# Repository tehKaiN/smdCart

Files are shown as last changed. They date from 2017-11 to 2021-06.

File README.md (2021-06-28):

# Custom Sega MegaDrive Cartridges

On this repo you will find schematics for SMD carts of various memory size. Each directory is dedicated to cart of given size.

## Current carts

- `512k` - 512 KByte cart based on 27c4001 chip. Home-etching friendly PCB design. Not tested!
- `1m_29f800` - 1 MByte cart based on 29f800 chip. Erasable/programmable using [ROMprg](https://github.com/tehKaiN/ROMprg) project.
- `2m_29f800` - **Untested!** 1-2 MByte cart based on 1-2 29f800 chips. Erasable/programmable using [ROMprg](https://github.com/tehKaiN/ROMprg) project.

## PCB Ordering instructions

MegaDrive carts have thickness of 1.6mm.

## Creating new cart

When designing PCBs for new cart, the most safe way to get proper dimensions is to copy them from other carts. Some notes:

- maximum cart height is about 60mm, otherwise it won't fit the case;
- distance between mechanical holes is 70mm
- mechanical holes should have diameter of about 6,75mm - add about 1mm for electroplating.
- there should be no soldermask around edge connector pins.

After creating new design and checking if it works, you are encouraged to submit pull request to this repo with your design.

## License

I dunno if MPL2.0 fits hardware, but the idea is that you should share your modifications of schematics / board layout.

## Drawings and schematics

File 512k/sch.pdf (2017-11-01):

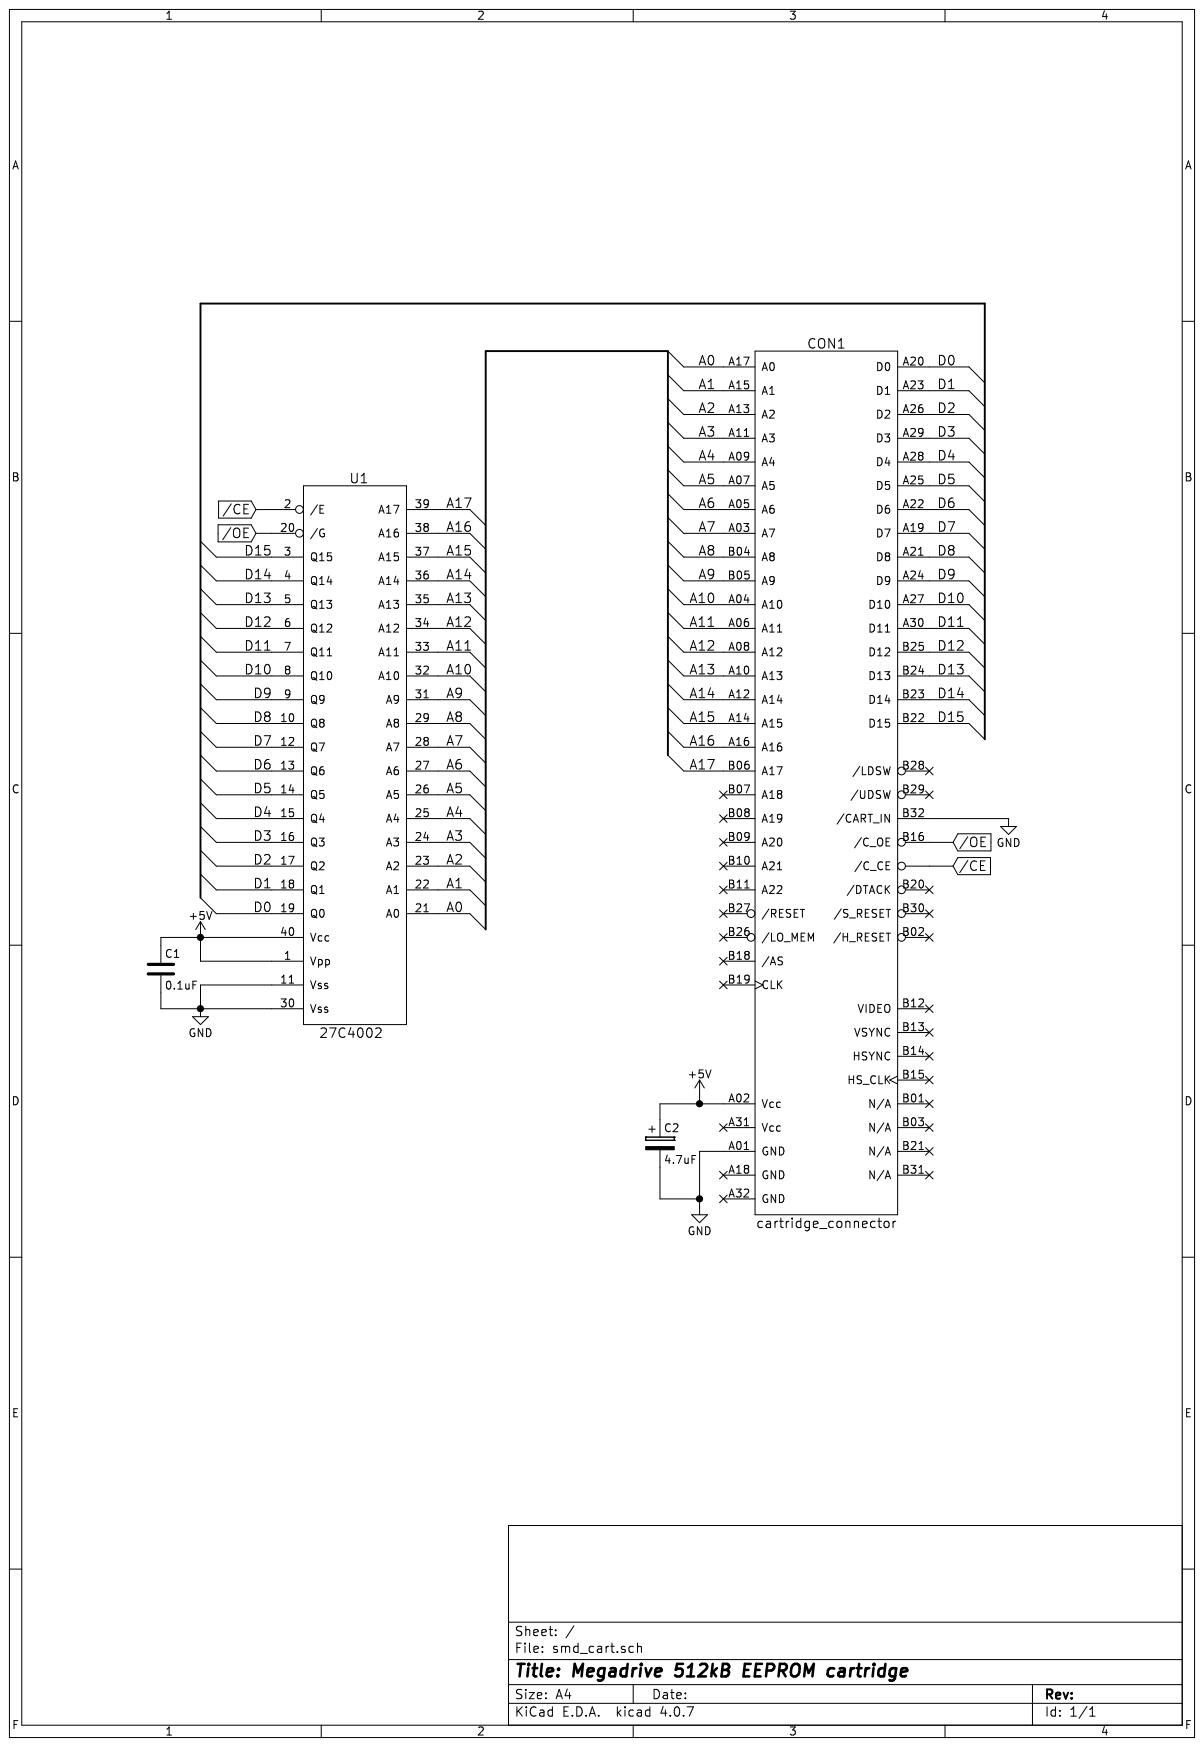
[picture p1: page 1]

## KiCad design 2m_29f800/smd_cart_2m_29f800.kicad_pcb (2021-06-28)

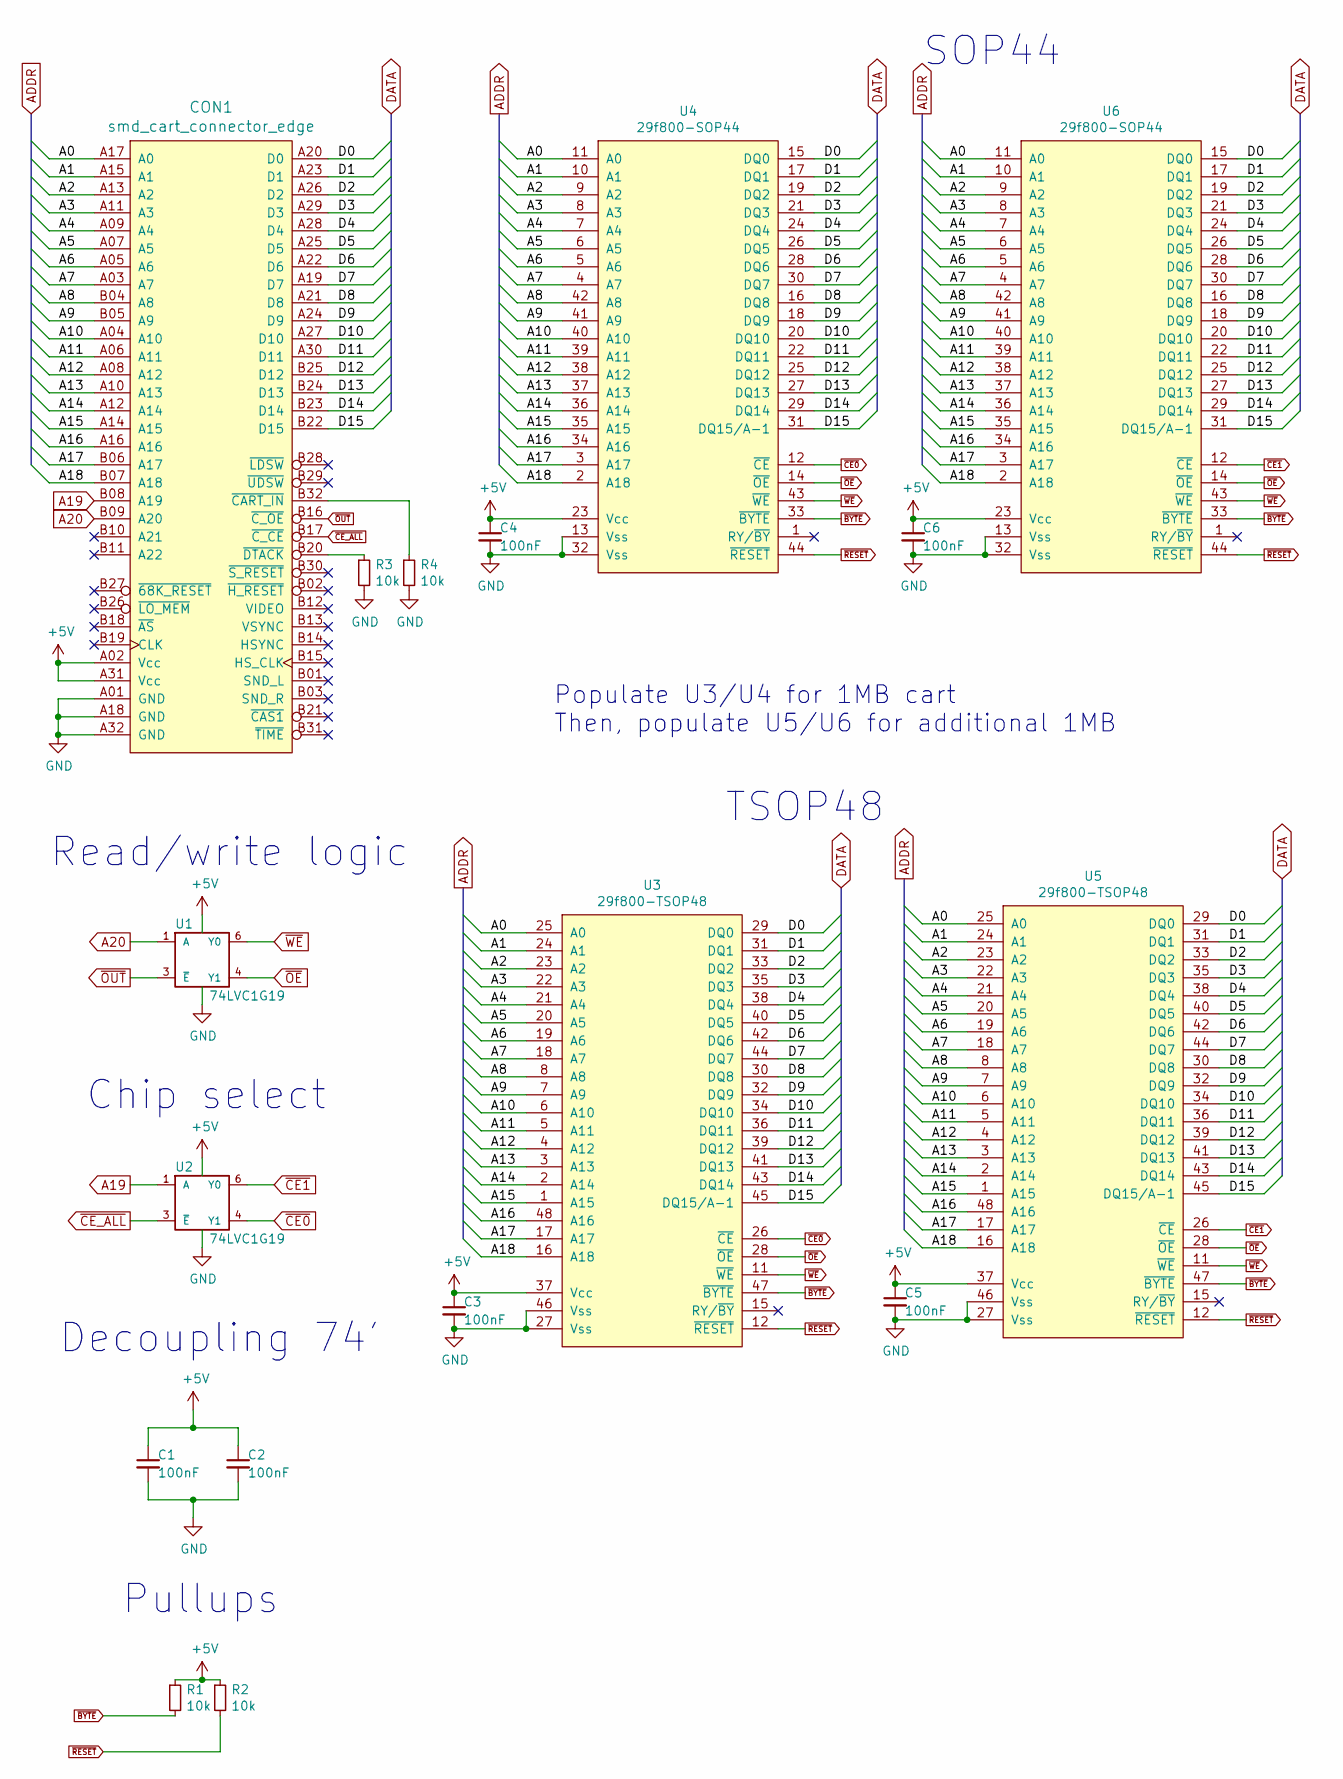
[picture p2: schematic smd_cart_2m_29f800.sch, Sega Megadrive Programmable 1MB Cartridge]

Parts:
C1, C2, C3, C4, C5, C6: 100nF; C_0805_2012Metric
CON1: smd_cart_connector_edge; md_cart_edge_conn
R1, R2, R3, R4: 10k; R_0805_2012Metric
U1, U2: 74LVC1G19; SOT-23-6
U3, U5: 29f800-TSOP48; TSOP-I-48_18.4x12mm_P0.5mm
U4, U6: 29f800-SOP44; SOIC-44

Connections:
+5V: C1.1, C2.1, C3.1, C4.1, C5.1, C6.1, CON1.A02 (Vcc), CON1.A31 (Vcc), R1.1, R2.1, U1.5 (VCC), U2.5 (VCC), U3.37 (Vcc), U4.23 (Vcc), U5.37 (Vcc), U6.23 (Vcc)
/A0: CON1.A17 (A0), U3.25 (A0), U4.11 (A0), U5.25 (A0), U6.11 (A0)
/A1: CON1.A15 (A1), U3.24 (A1), U4.10 (A1), U5.24 (A1), U6.10 (A1)
/A2: CON1.A13 (A2), U3.23 (A2), U4.9 (A2), U5.23 (A2), U6.9 (A2)
/A3: CON1.A11 (A3), U3.22 (A3), U4.8 (A3), U5.22 (A3), U6.8 (A3)
/A4: CON1.A09 (A4), U3.21 (A4), U4.7 (A4), U5.21 (A4), U6.7 (A4)
/A5: CON1.A07 (A5), U3.20 (A5), U4.6 (A5), U5.20 (A5), U6.6 (A5)
/A6: CON1.A05 (A6), U3.19 (A6), U4.5 (A6), U5.19 (A6), U6.5 (A6)
/A7: CON1.A03 (A7), U3.18 (A7), U4.4 (A7), U5.18 (A7), U6.4 (A7)
/A8: CON1.B04 (A8), U3.8 (A8), U4.42 (A8), U5.8 (A8), U6.42 (A8)
/A9: CON1.B05 (A9), U3.7 (A9), U4.41 (A9), U5.7 (A9), U6.41 (A9)
/A10: CON1.A04 (A10), U3.6 (A10), U4.40 (A10), U5.6 (A10), U6.40 (A10)
/A11: CON1.A06 (A11), U3.5 (A11), U4.39 (A11), U5.5 (A11), U6.39 (A11)
/A12: CON1.A08 (A12), U3.4 (A12), U4.38 (A12), U5.4 (A12), U6.38 (A12)
/A13: CON1.A10 (A13), U3.3 (A13), U4.37 (A13), U5.3 (A13), U6.37 (A13)
/A14: CON1.A12 (A14), U3.2 (A14), U4.36 (A14), U5.2 (A14), U6.36 (A14)
/A15: CON1.A14 (A15), U3.1 (A15), U4.35 (A15), U5.1 (A15), U6.35 (A15)
/A16: CON1.A16, U3.48 (A16), U4.34 (A16), U5.48 (A16), U6.34 (A16)
/A17: CON1.B06 (A17), U3.17 (A17), U4.3 (A17), U5.17 (A17), U6.3 (A17)
/A18: CON1.B07 (A18), U3.16 (A18), U4.2 (A18), U5.16 (A18), U6.2 (A18)
/D0: CON1.A20 (D0), U3.29 (DQ0), U4.15 (DQ0), U5.29 (DQ0), U6.15 (DQ0)
/D1: CON1.A23 (D1), U3.31 (DQ1), U4.17 (DQ1), U5.31 (DQ1), U6.17 (DQ1)
/D2: CON1.A26 (D2), U3.33 (DQ2), U4.19 (DQ2), U5.33 (DQ2), U6.19 (DQ2)
/D3: CON1.A29 (D3), U3.35 (DQ3), U4.21 (DQ3), U5.35 (DQ3), U6.21 (DQ3)
/D4: CON1.A28 (D4), U3.38 (DQ4), U4.24 (DQ4), U5.38 (DQ4), U6.24 (DQ4)
/D5: CON1.A25 (D5), U3.40 (DQ5), U4.26 (DQ5), U5.40 (DQ5), U6.26 (DQ5)
/D6: CON1.A22 (D6), U3.42 (DQ6), U4.28 (DQ6), U5.42 (DQ6), U6.28 (DQ6)
/D7: CON1.A19 (D7), U3.44 (DQ7), U4.30 (DQ7), U5.44 (DQ7), U6.30 (DQ7)
/D8: CON1.A21 (D8), U3.30 (DQ8), U4.16 (DQ8), U5.30 (DQ8), U6.16 (DQ8)
/D9: CON1.A24 (D9), U3.32 (DQ9), U4.18 (DQ9), U5.32 (DQ9), U6.18 (DQ9)
/D10: CON1.A27 (D10), U3.34 (DQ10), U4.20 (DQ10), U5.34 (DQ10), U6.20 (DQ10)
/D11: CON1.A30 (D11), U3.36 (DQ11), U4.22 (DQ11), U5.36 (DQ11), U6.22 (DQ11)
/D12: CON1.B25 (D12), U3.39 (DQ12), U4.25 (DQ12), U5.39 (DQ12), U6.25 (DQ12)
/D13: CON1.B24 (D13), U3.41 (DQ13), U4.27 (DQ13), U5.41 (DQ13), U6.27 (DQ13)
/D14: CON1.B23 (D14), U3.43 (DQ14), U4.29 (DQ14), U5.43 (DQ14), U6.29 (DQ14)
/D15: CON1.B22 (D15), U3.45 (DQ15/A-1), U4.31 (DQ15/A-1), U5.45 (DQ15/A-1), U6.31 (DQ15/A-1)
A19: CON1.B08 (A19), U2.1 (A)
A20: CON1.B09 (A20), U1.1 (A)
GND: C1.2, C2.2, C3.2, C4.2, C5.2, C6.2, CON1.A01 (GND), CON1.A18 (GND), CON1.A32 (GND), R3.2, R4.2, U1.2 (GND), U2.2 (GND), U3.27 (Vss), U3.46 (Vss), U4.13 (Vss), U4.32 (Vss), U5.27 (Vss), U5.46 (Vss), U6.13 (Vss), U6.32 (Vss)
unnamed: CON1.B20 (~DTACK), R3.1
unnamed: CON1.B32 (~CART_IN), R4.1
~BYTE: R1.2, U3.47 (~BYTE), U4.33 (~BYTE), U5.47 (~BYTE), U6.33 (~BYTE)
~CE0: U2.4 (Y1), U3.26 (~CE), U4.12 (~CE)
~CE1: U2.6 (Y0), U5.26 (~CE), U6.12 (~CE)
~CE_ALL: CON1.B17 (~C_CE), U2.3 (~E)
~OE: U1.4 (Y1), U3.28 (~OE), U4.14 (~OE), U5.28 (~OE), U6.14 (~OE)
~OUT: CON1.B16 (~C_OE), U1.3 (~E)
~RESET: R2.2, U3.12 (~RESET), U4.44 (~RESET), U5.12 (~RESET), U6.44 (~RESET)
~WE: U1.6 (Y0), U3.11 (~WE), U4.43 (~WE), U5.11 (~WE), U6.43 (~WE)

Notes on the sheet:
SOP44
TSOP48
Read/write logic
Decoupling 74'
Chip select
Pullups
Populate U3/U4 for 1MB cart Then, populate U5/U6 for additional 1MB

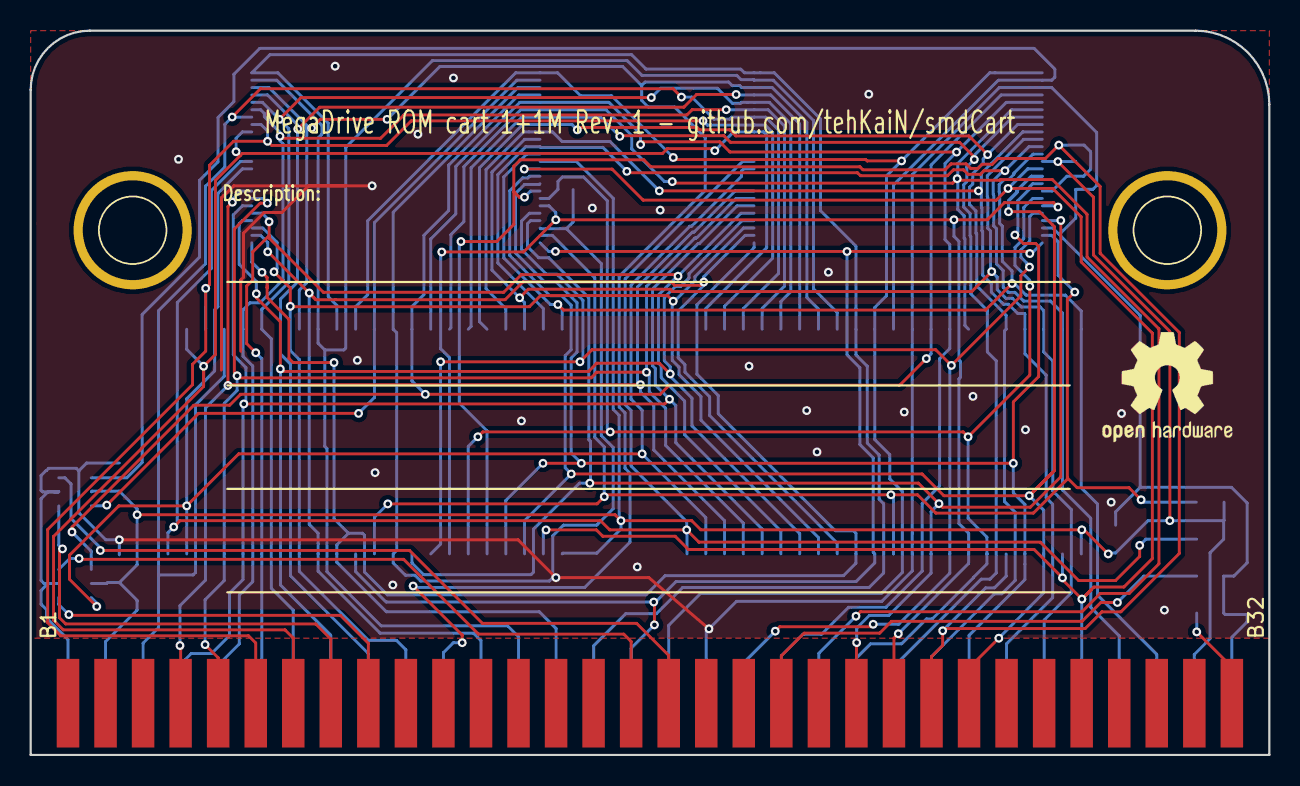
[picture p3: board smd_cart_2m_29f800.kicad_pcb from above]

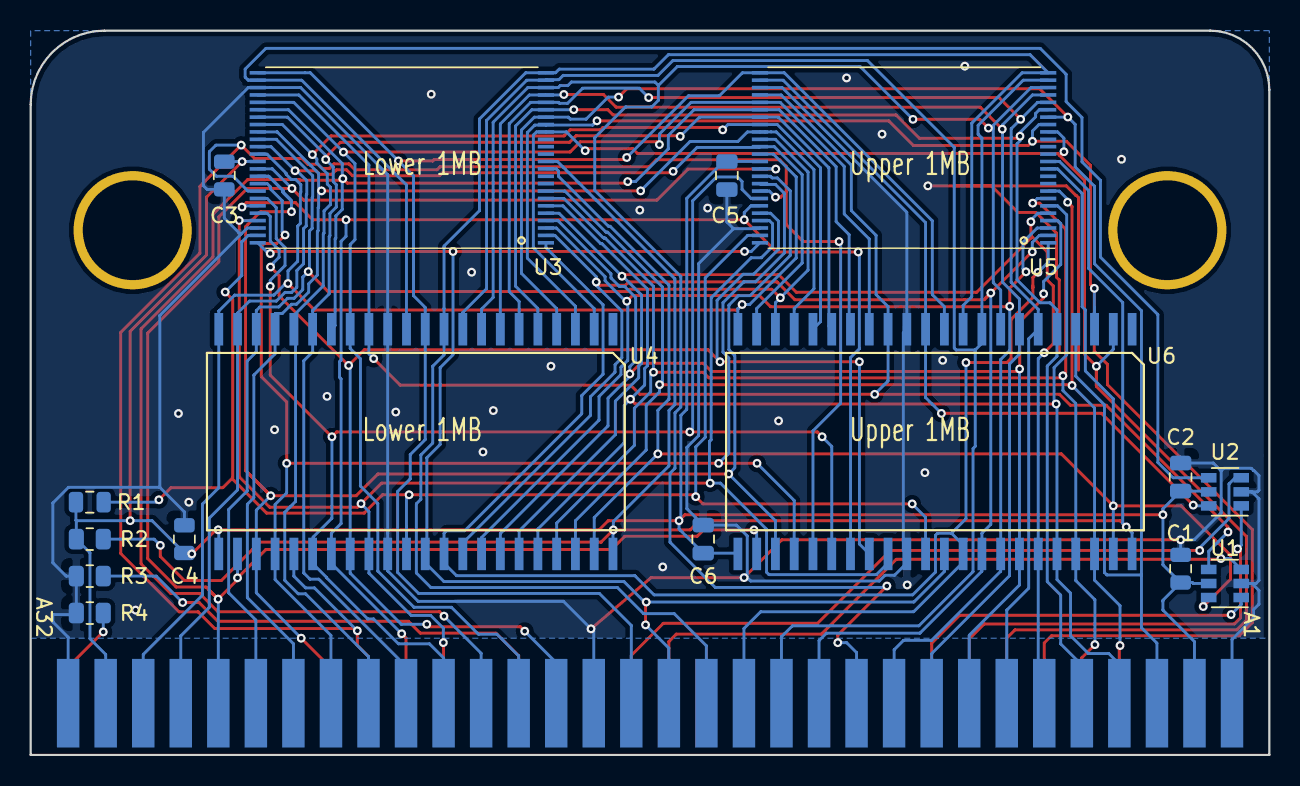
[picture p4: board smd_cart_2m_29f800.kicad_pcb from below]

Board: 2 copper layers, 83.8 x 49.0 mm, 19 parts (16 on the bottom side), 49 nets.

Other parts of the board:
DRL1, DRL2: 1pin

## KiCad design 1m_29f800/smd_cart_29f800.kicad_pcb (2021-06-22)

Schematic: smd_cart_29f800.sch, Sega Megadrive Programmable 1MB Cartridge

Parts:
C1, C2, C3: 100nF; C_0805_2012Metric
CON1: smd_cart_connector_edge; md_cart_edge_conn
R1, R2, R3, R4, R5, R6: 10k; R_0805_2012Metric
U1: 74HCT00; SOIC-14_3.9x8.7mm_P1.27mm
U2: 29f800-TSOP48; TSOP-I-48_18.4x12mm_P0.5mm
U3: 29f800-SOP44; SOIC-44

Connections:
+5V: C1.1, C2.1, C3.1, CON1.A02, CON1.A31, R3.1, R4.1, R5.1, R6.1, U1.14 (VCC), U2.37, U3.23
/A0: CON1.A17, U2.25, U3.11
/A1: CON1.A15, U2.24, U3.10
/A2: CON1.A13, U2.23, U3.9
/A3: CON1.A11, U2.22, U3.8
/A4: CON1.A09, U2.21, U3.7
/A5: CON1.A07, U2.20, U3.6
/A6: CON1.A05, U2.19, U3.5
/A7: CON1.A03, U2.18, U3.4
/A8: CON1.B04, U2.8, U3.42
/A9: CON1.B05, U2.7, U3.41
/A10: CON1.A04, U2.6, U3.40
/A11: CON1.A06, U2.5, U3.39
/A12: CON1.A08, U2.4, U3.38
/A13: CON1.A10, U2.3, U3.37
/A14: CON1.A12, U2.2, U3.36
/A15: CON1.A14, U2.1, U3.35
/A16: CON1.A16, U2.48, U3.34
/A17: CON1.B06, U2.17, U3.3
/A18: CON1.B07, U2.16, U3.2
/D0: CON1.A20, U2.29, U3.15
/D1: CON1.A23, U2.31, U3.17
/D2: CON1.A26, U2.33, U3.19
/D3: CON1.A29, U2.35, U3.21
/D4: CON1.A28, U2.38, U3.24
/D5: CON1.A25, U2.40, U3.26
/D6: CON1.A22, U2.42, U3.28
/D7: CON1.A19, U2.44, U3.30
/D8: CON1.A21, U2.30, U3.16
/D9: CON1.A24, U2.32, U3.18
/D10: CON1.A27, U2.34, U3.20
/D11: CON1.A30, U2.36, U3.22
/D12: CON1.B25, U2.39, U3.25
/D13: CON1.B24, U2.41, U3.27
/D14: CON1.B23, U2.43, U3.29
/D15: CON1.B22, U2.45, U3.31
/OUT: U1.3, U1.5, U1.12
/~A20: U1.8, U1.13
A20: CON1.B09, U1.4, U1.9, U1.10
GND: C1.2, C2.2, C3.2, CON1.A01, CON1.A18, CON1.A32, R1.2, R2.2, U1.7 (GND), U2.27, U2.46, U3.13, U3.32
unnamed: CON1.B20, R1.1
unnamed: CON1.B32, R2.1
unnamed: R3.2, U2.47
unnamed: R4.2, U3.33
unnamed: R5.2, U2.12
unnamed: R6.2, U3.44
~CE: CON1.B17, U2.26, U3.12
~OE: U1.11, U2.28, U3.14
~OUT: CON1.B16, U1.1, U1.2
~WE: U1.6, U2.11, U3.43

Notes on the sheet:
SOP44
TSOP48
Read/write logic
Decoupling

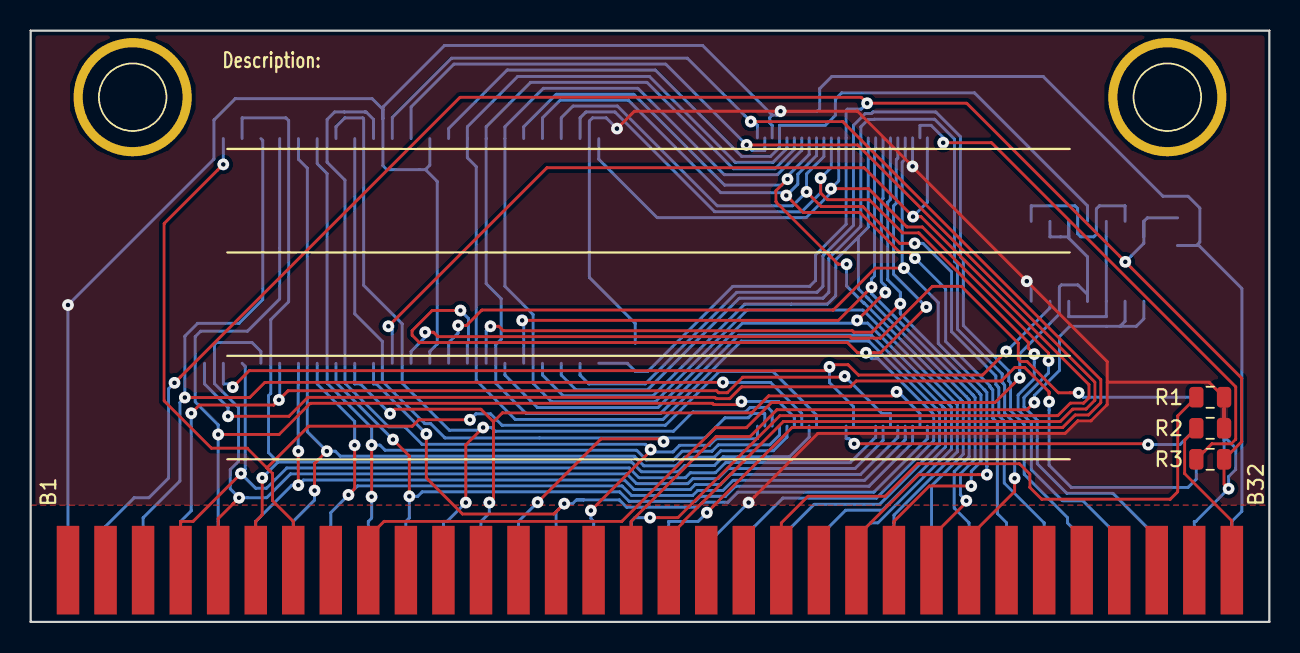
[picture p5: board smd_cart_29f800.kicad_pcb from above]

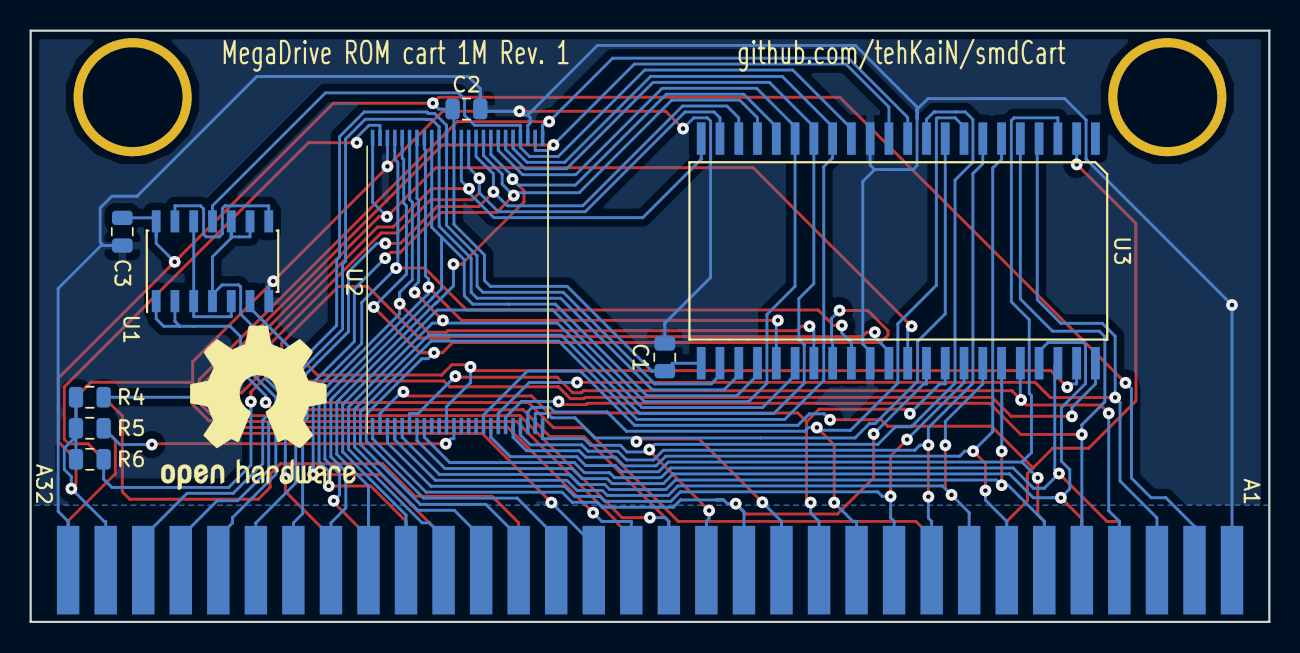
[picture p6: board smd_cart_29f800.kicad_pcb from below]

Board: 2 copper layers, 83.8 x 40.0 mm, 15 parts (9 on the bottom side), 50 nets.

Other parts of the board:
DRL1, DRL2: 1pin

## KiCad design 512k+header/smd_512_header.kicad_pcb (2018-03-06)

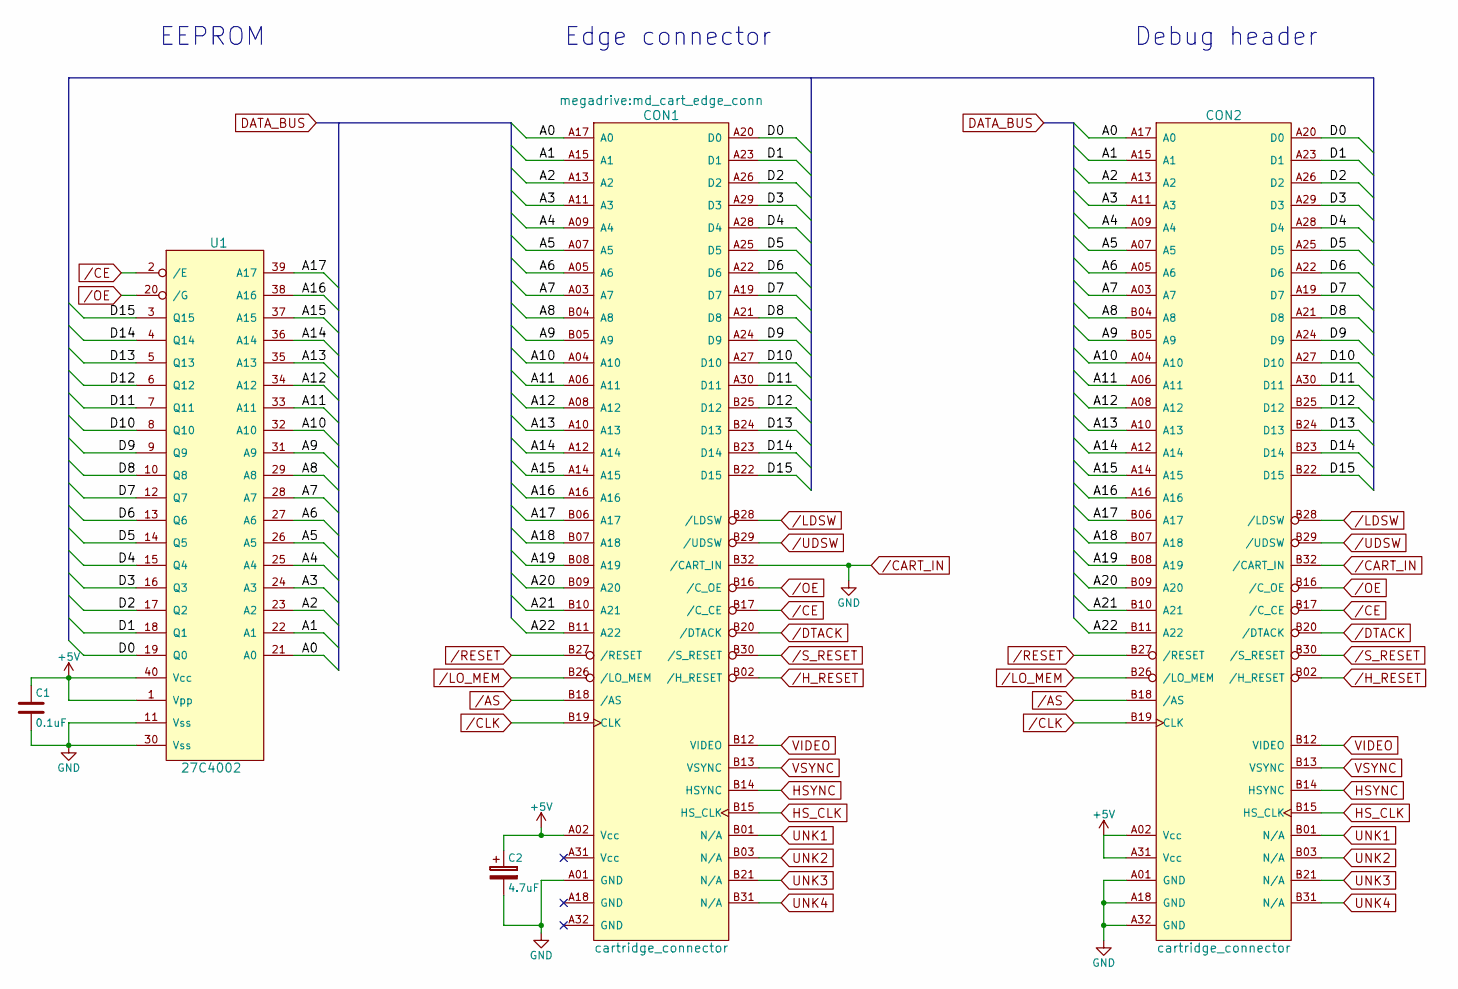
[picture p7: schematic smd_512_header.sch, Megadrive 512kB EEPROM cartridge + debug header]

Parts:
C1: 0.1uF; C_0805_HandSoldering
C2: 4.7uF; CP_Radial_D4.0mm_P1.50mm
CON1: cartridge_connector; md_cart_edge_conn
CON2: cartridge_connector; md_cart_edge_conn_desc
U1: 27C4002; DIP-40_W15.24mm_Socket_LongPads

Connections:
+5V: C1.1, C2.1, CON1.A02 (Vcc), CON2.A02 (Vcc), CON2.A31 (Vcc), U1.1 (Vpp), U1.40 (Vcc)
/A0: CON1.A17 (A0), CON2.A17 (A0), U1.21 (A0)
/A1: CON1.A15 (A1), CON2.A15 (A1), U1.22 (A1)
/A2: CON1.A13 (A2), CON2.A13 (A2), U1.23 (A2)
/A3: CON1.A11 (A3), CON2.A11 (A3), U1.24 (A3)
/A4: CON1.A09 (A4), CON2.A09 (A4), U1.25 (A4)
/A5: CON1.A07 (A5), CON2.A07 (A5), U1.26 (A5)
/A6: CON1.A05 (A6), CON2.A05 (A6), U1.27 (A6)
/A7: CON1.A03 (A7), CON2.A03 (A7), U1.28 (A7)
/A8: CON1.B04 (A8), CON2.B04 (A8), U1.29 (A8)
/A9: CON1.B05 (A9), CON2.B05 (A9), U1.31 (A9)
/A10: CON1.A04 (A10), CON2.A04 (A10), U1.32 (A10)
/A11: CON1.A06 (A11), CON2.A06 (A11), U1.33 (A11)
/A12: CON1.A08 (A12), CON2.A08 (A12), U1.34 (A12)
/A13: CON1.A10 (A13), CON2.A10 (A13), U1.35 (A13)
/A14: CON1.A12 (A14), CON2.A12 (A14), U1.36 (A14)
/A15: CON1.A14 (A15), CON2.A14 (A15), U1.37 (A15)
/A16: CON1.A16, CON2.A16, U1.38 (A16)
/A17: CON1.B06 (A17), CON2.B06 (A17), U1.39 (A17)
/A18: CON1.B07 (A18), CON2.B07 (A18)
/A19: CON1.B08 (A19), CON2.B08 (A19)
/A20: CON1.B09 (A20), CON2.B09 (A20)
/A21: CON1.B10 (A21), CON2.B10 (A21)
/A22: CON1.B11 (A22), CON2.B11 (A22)
/AS: CON1.B18 (/AS), CON2.B18 (/AS)
/CART_IN: C1.2, C2.2, CON1.A01 (GND), CON1.B32 (/CART_IN), CON2.A01 (GND), CON2.A18 (GND), CON2.A32 (GND), CON2.B32 (/CART_IN), U1.11 (Vss), U1.30 (Vss)
/CE: CON1.B17 (/C_CE), CON2.B17 (/C_CE), U1.2 (/E)
/CLK: CON1.B19 (CLK), CON2.B19 (CLK)
/D0: CON1.A20 (D0), CON2.A20 (D0), U1.19 (Q0)
/D1: CON1.A23 (D1), CON2.A23 (D1), U1.18 (Q1)
/D2: CON1.A26 (D2), CON2.A26 (D2), U1.17 (Q2)
/D3: CON1.A29 (D3), CON2.A29 (D3), U1.16 (Q3)
/D4: CON1.A28 (D4), CON2.A28 (D4), U1.15 (Q4)
/D5: CON1.A25 (D5), CON2.A25 (D5), U1.14 (Q5)
/D6: CON1.A22 (D6), CON2.A22 (D6), U1.13 (Q6)
/D7: CON1.A19 (D7), CON2.A19 (D7), U1.12 (Q7)
/D8: CON1.A21 (D8), CON2.A21 (D8), U1.10 (Q8)
/D9: CON1.A24 (D9), CON2.A24 (D9), U1.9 (Q9)
/D10: CON1.A27 (D10), CON2.A27 (D10), U1.8 (Q10)
/D11: CON1.A30 (D11), CON2.A30 (D11), U1.7 (Q11)
/D12: CON1.B25 (D12), CON2.B25 (D12), U1.6 (Q12)
/D13: CON1.B24 (D13), CON2.B24 (D13), U1.5 (Q13)
/D14: CON1.B23 (D14), CON2.B23 (D14), U1.4 (Q14)
/D15: CON1.B22 (D15), CON2.B22 (D15), U1.3 (Q15)
/DTACK: CON1.B20 (/DTACK), CON2.B20 (/DTACK)
/H_RESET: CON1.B02 (/H_RESET), CON2.B02 (/H_RESET)
/LDSW: CON1.B28 (/LDSW), CON2.B28 (/LDSW)
/LO_MEM: CON1.B26 (/LO_MEM), CON2.B26 (/LO_MEM)
/OE: CON1.B16 (/C_OE), CON2.B16 (/C_OE), U1.20 (/G)
/RESET: CON1.B27 (/RESET), CON2.B27 (/RESET)
/S_RESET: CON1.B30 (/S_RESET), CON2.B30 (/S_RESET)
/UDSW: CON1.B29 (/UDSW), CON2.B29 (/UDSW)
HSYNC: CON1.B14 (HSYNC), CON2.B14 (HSYNC)
HS_CLK: CON1.B15 (HS_CLK), CON2.B15 (HS_CLK)
UNK1: CON1.B01 (N/A), CON2.B01 (N/A)
UNK2: CON1.B03 (N/A), CON2.B03 (N/A)
UNK3: CON1.B21 (N/A), CON2.B21 (N/A)
UNK4: CON1.B31 (N/A), CON2.B31 (N/A)
VIDEO: CON1.B12 (VIDEO), CON2.B12 (VIDEO)
VSYNC: CON1.B13 (VSYNC), CON2.B13 (VSYNC)

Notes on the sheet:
Edge connector
EEPROM
Debug header

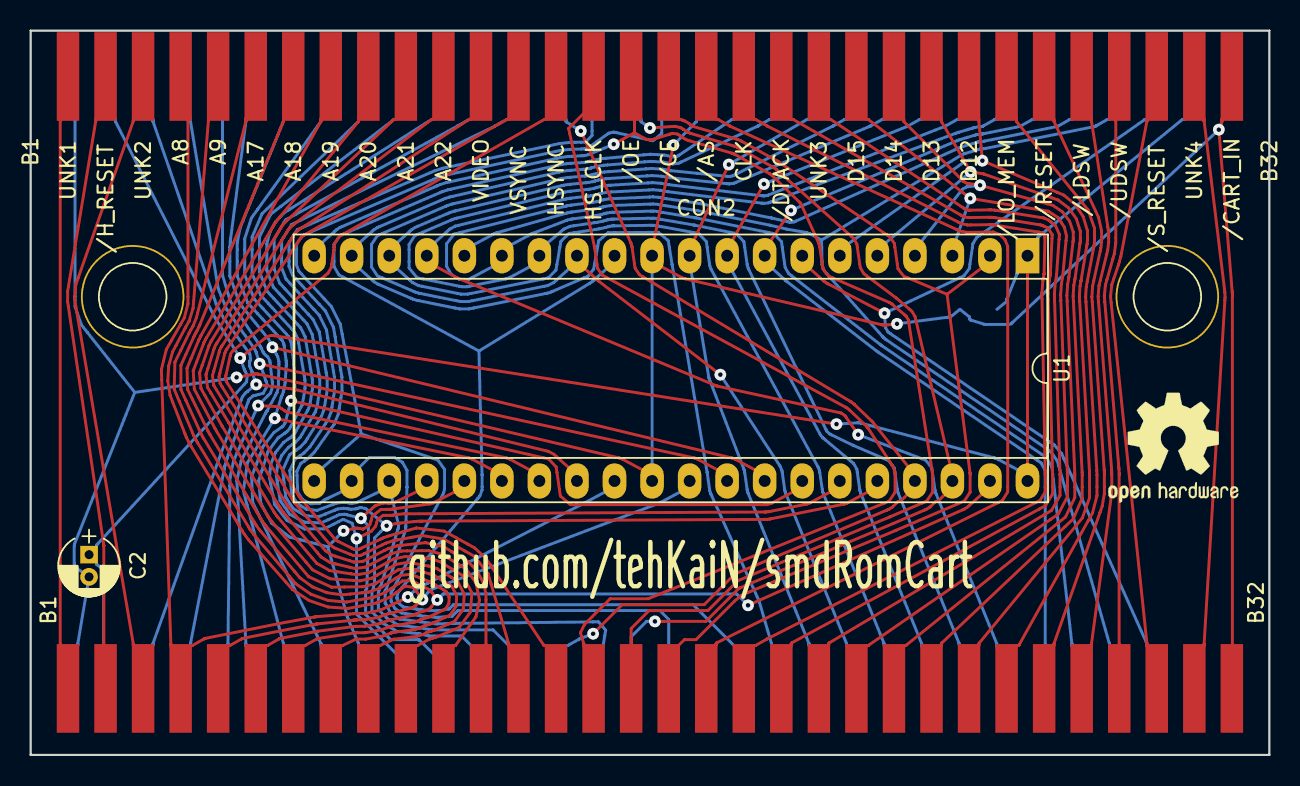
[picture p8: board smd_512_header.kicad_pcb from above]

Board: 2 copper layers, 83.8 x 49.0 mm, 8 parts (1 on the bottom side), 60 nets.

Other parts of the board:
DRL1, DRL2: 1pin
LOGO2: OSHW-Logo2_9.8x8mm_SilkScreen

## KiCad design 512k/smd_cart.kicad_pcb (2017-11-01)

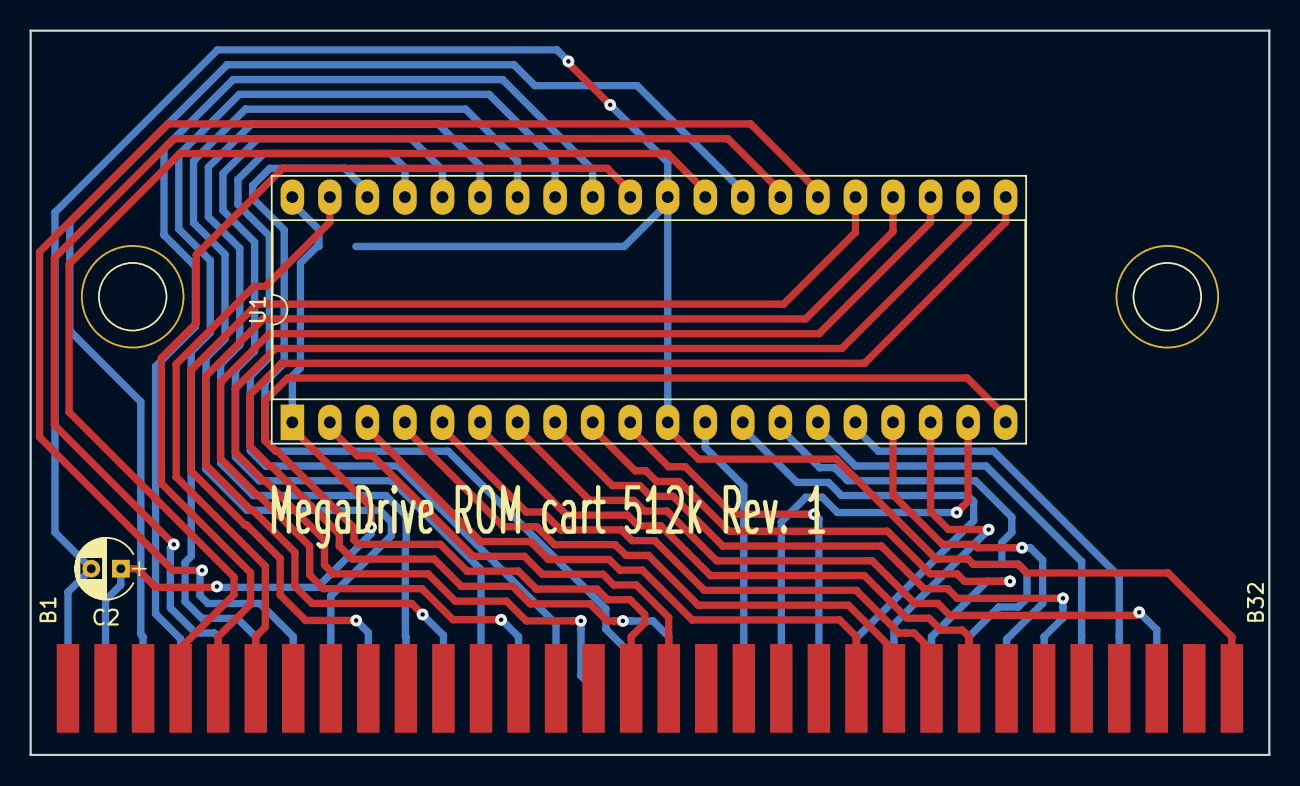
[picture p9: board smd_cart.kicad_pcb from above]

Board: 2 copper layers, 83.8 x 49.0 mm, 4 parts (1 on the bottom side), 38 nets.

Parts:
C1: 0.1uF; C_0805_HandSoldering
C2: 4.7uF; CP_Radial_D4.0mm_P2.00mm
CON1: cartridge_connector; md_cart_edge_conn
U1: 27C4002; DIP-40_W15.24mm_Socket_LongPads

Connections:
+5V: C1.1, C2.1, CON1.A02, U1.1, U1.40
/A0: CON1.A17, U1.21
/A1: CON1.A15, U1.22
/A2: CON1.A13, U1.23
/A3: CON1.A11, U1.24
/A4: CON1.A09, U1.25
/A5: CON1.A07, U1.26
/A6: CON1.A05, U1.27
/A7: CON1.A03, U1.28
/A8: CON1.B04, U1.29
/A9: CON1.B05, U1.31
/A10: CON1.A04, U1.32
/A11: CON1.A06, U1.33
/A12: CON1.A08, U1.34
/A13: CON1.A10, U1.35
/A14: CON1.A12, U1.36
/A15: CON1.A14, U1.37
/A16: CON1.A16, U1.38
/A17: CON1.B06, U1.39
/CE: CON1.B17, U1.2
/D0: CON1.A20, U1.19
/D1: CON1.A23, U1.18
/D2: CON1.A26, U1.17
/D3: CON1.A29, U1.16
/D4: CON1.A28, U1.15
/D5: CON1.A25, U1.14
/D6: CON1.A22, U1.13
/D7: CON1.A19, U1.12
/D8: CON1.A21, U1.10
/D9: CON1.A24, U1.9
/D10: CON1.A27, U1.8
/D11: CON1.A30, U1.7
/D12: CON1.B25, U1.6
/D13: CON1.B24, U1.5
/D14: CON1.B23, U1.4
/D15: CON1.B22, U1.3
/OE: CON1.B16, U1.20
GND: C1.2, C2.2, CON1.A01, CON1.B32, U1.11, U1.30

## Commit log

2017-11-01 Added 512k cartridge
    [smd_cart.kicad_pcb, smd_cart.sch]
2018-03-06 Added edge connector with description & pin-variant
2018-03-06 Added 512k cart with debug header
    [smd_512_header.dsn, smd_512_header.kicad_pcb, smd_512_header.sch]
2018-03-06 Added 2 missing pin descriptions on footprint md_cart_endge_conn_desc
    [smd_512_header.kicad_pcb]
2018-09-09 Updated cart connector symbols, added slot symbol
2018-09-10 Added footprint for cartridge slot
2018-09-11 changed license to MPL2.0
    [smd_512_header.dsn]
2018-09-11 Initial routing of 29f800 cart, could be done better
    [smd_cart_29f800.kicad_pcb, smd_cart_29f800.sch]
2021-06-22 fixed library paths
    [smd_cart_29f800.kicad_pcb]
2021-06-28 added 2MB experimental cart
    [smd_cart_2m_29f800.kicad_pcb, smd_cart_2m_29f800.sch]
